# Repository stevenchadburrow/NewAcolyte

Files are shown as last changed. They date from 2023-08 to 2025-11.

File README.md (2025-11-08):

# NewAcolyte

This is the New Acolyte microcomputer.  

It runs a W65C02 microprocessor at 6.29 MHz, and has 64 KB of RAM and 32 KB of ROM available.  It can output 16-colors at a 256x240 resolution, or 4-colors at 512x240 resolution.  It supports PS/2 Keyboard and Mouse, Genesis Gamepad, square wave audio output, and SD Card through SPI adapter.  This New Acolyte uses the Xilinx XC9572XL CLPD, programmed using Xilinx ISE and 'xc3sprog'.  

Currently it's software includes the Scratchpad, Monitor, BASIC, and games including Tetra, Intruders, Missile, Galian, and Knave.

(Bodge wire connects V-SYNC to /NMI. Additional pull-up resistors on JOY-UP, JOY-DOWN, JOY-BUTTON1, and JOY-BUTTON2. Additional pull-down resistor on ROM-BANK.)

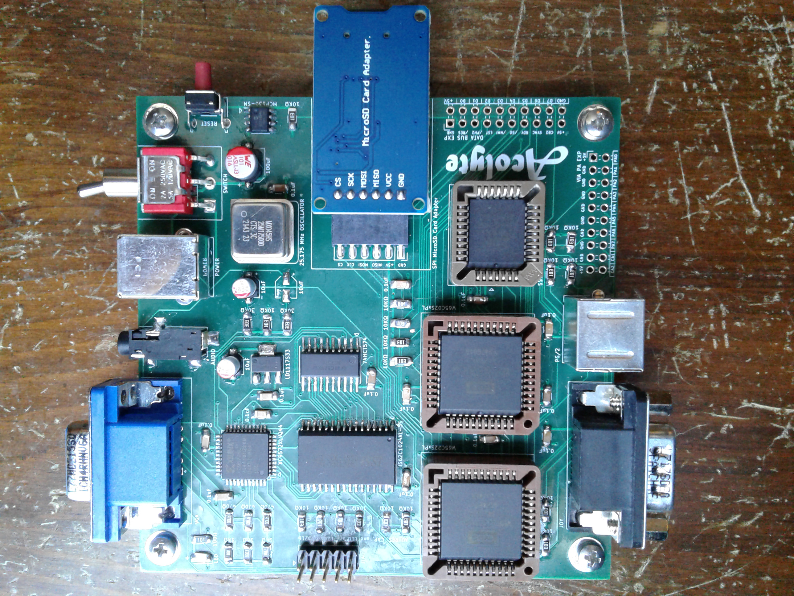
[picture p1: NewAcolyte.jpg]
<br>
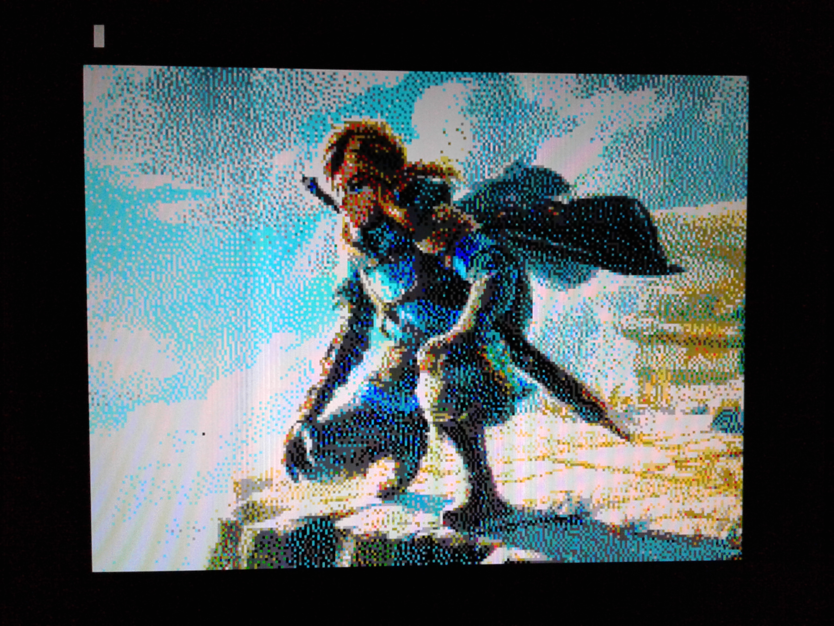
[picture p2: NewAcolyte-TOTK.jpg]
<br>
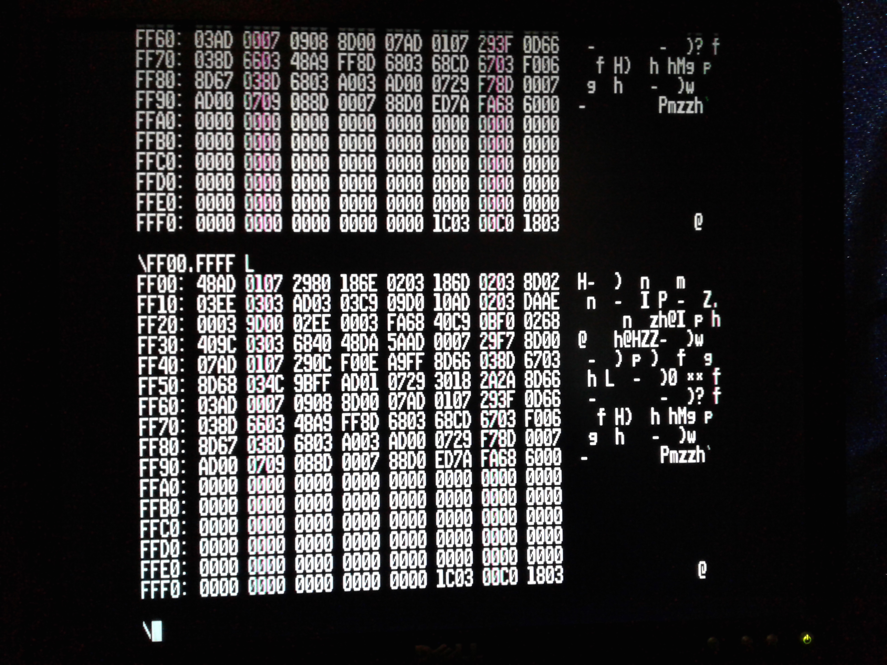
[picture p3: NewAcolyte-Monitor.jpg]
<br>
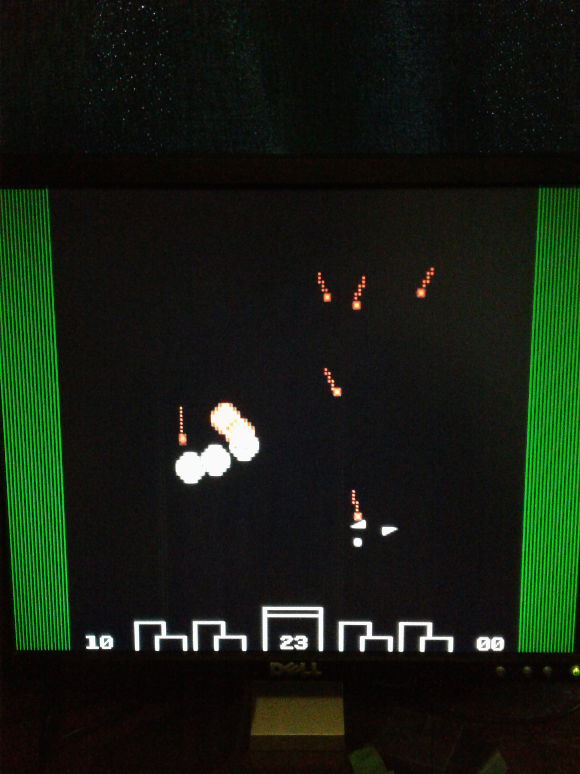
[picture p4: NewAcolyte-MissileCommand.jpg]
<br>
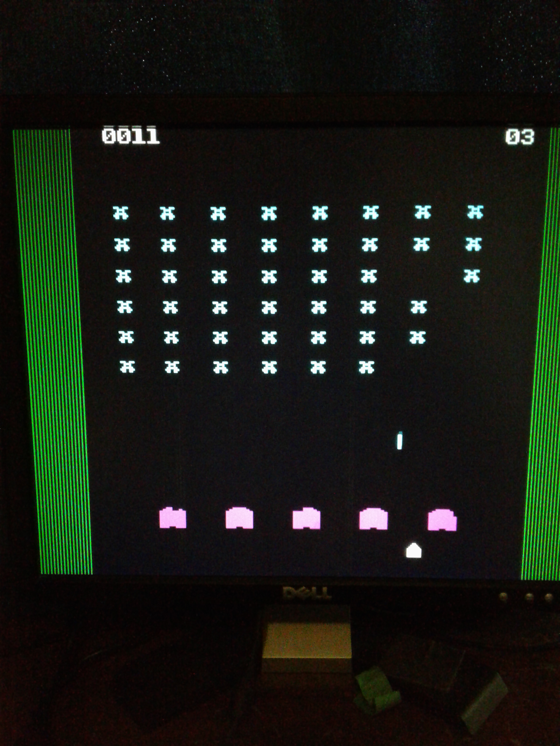
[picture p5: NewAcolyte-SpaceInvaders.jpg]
<br>

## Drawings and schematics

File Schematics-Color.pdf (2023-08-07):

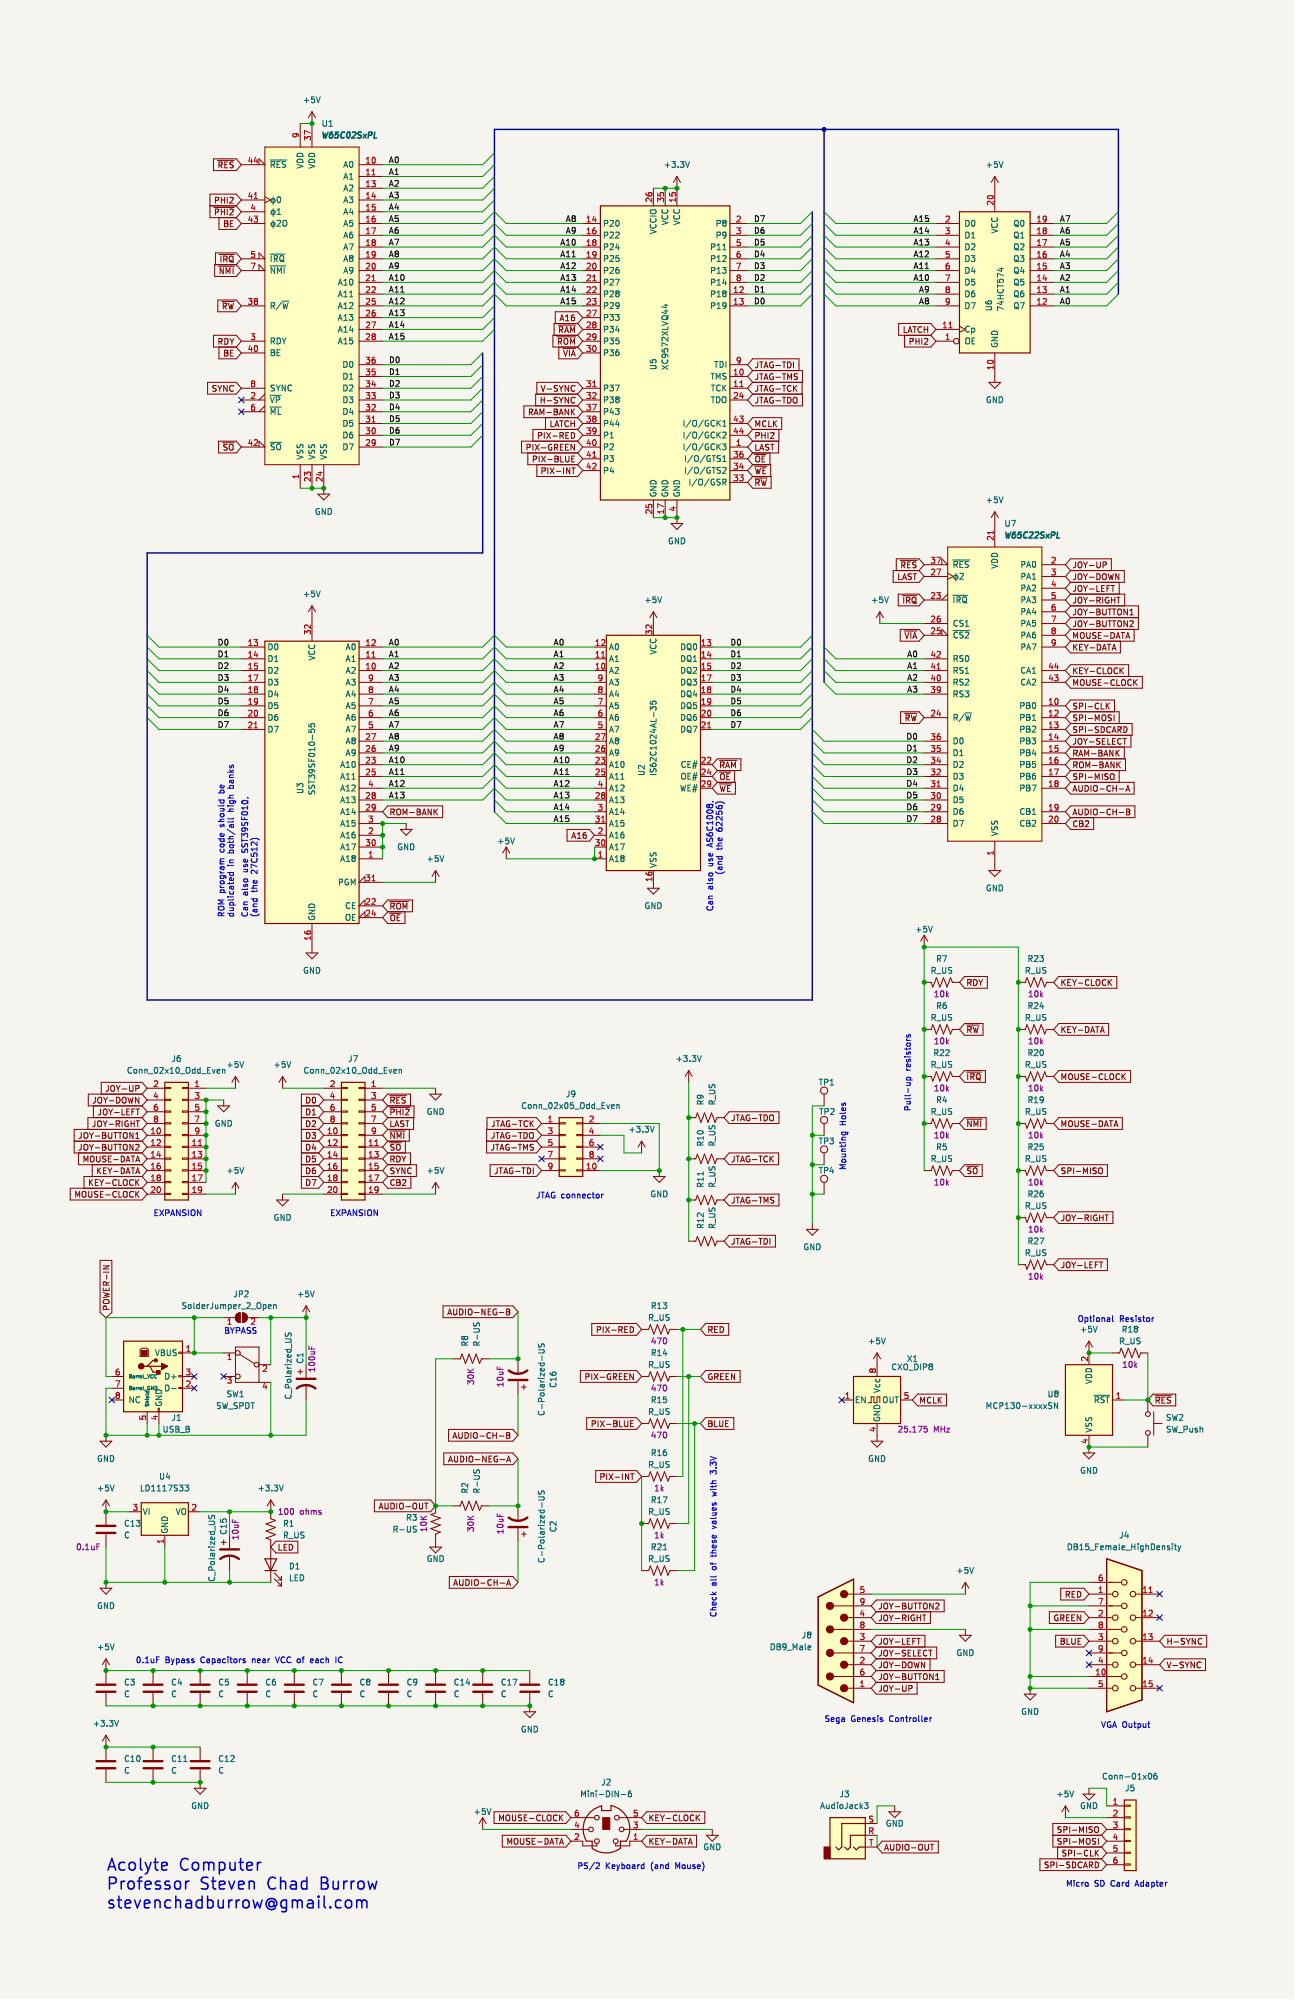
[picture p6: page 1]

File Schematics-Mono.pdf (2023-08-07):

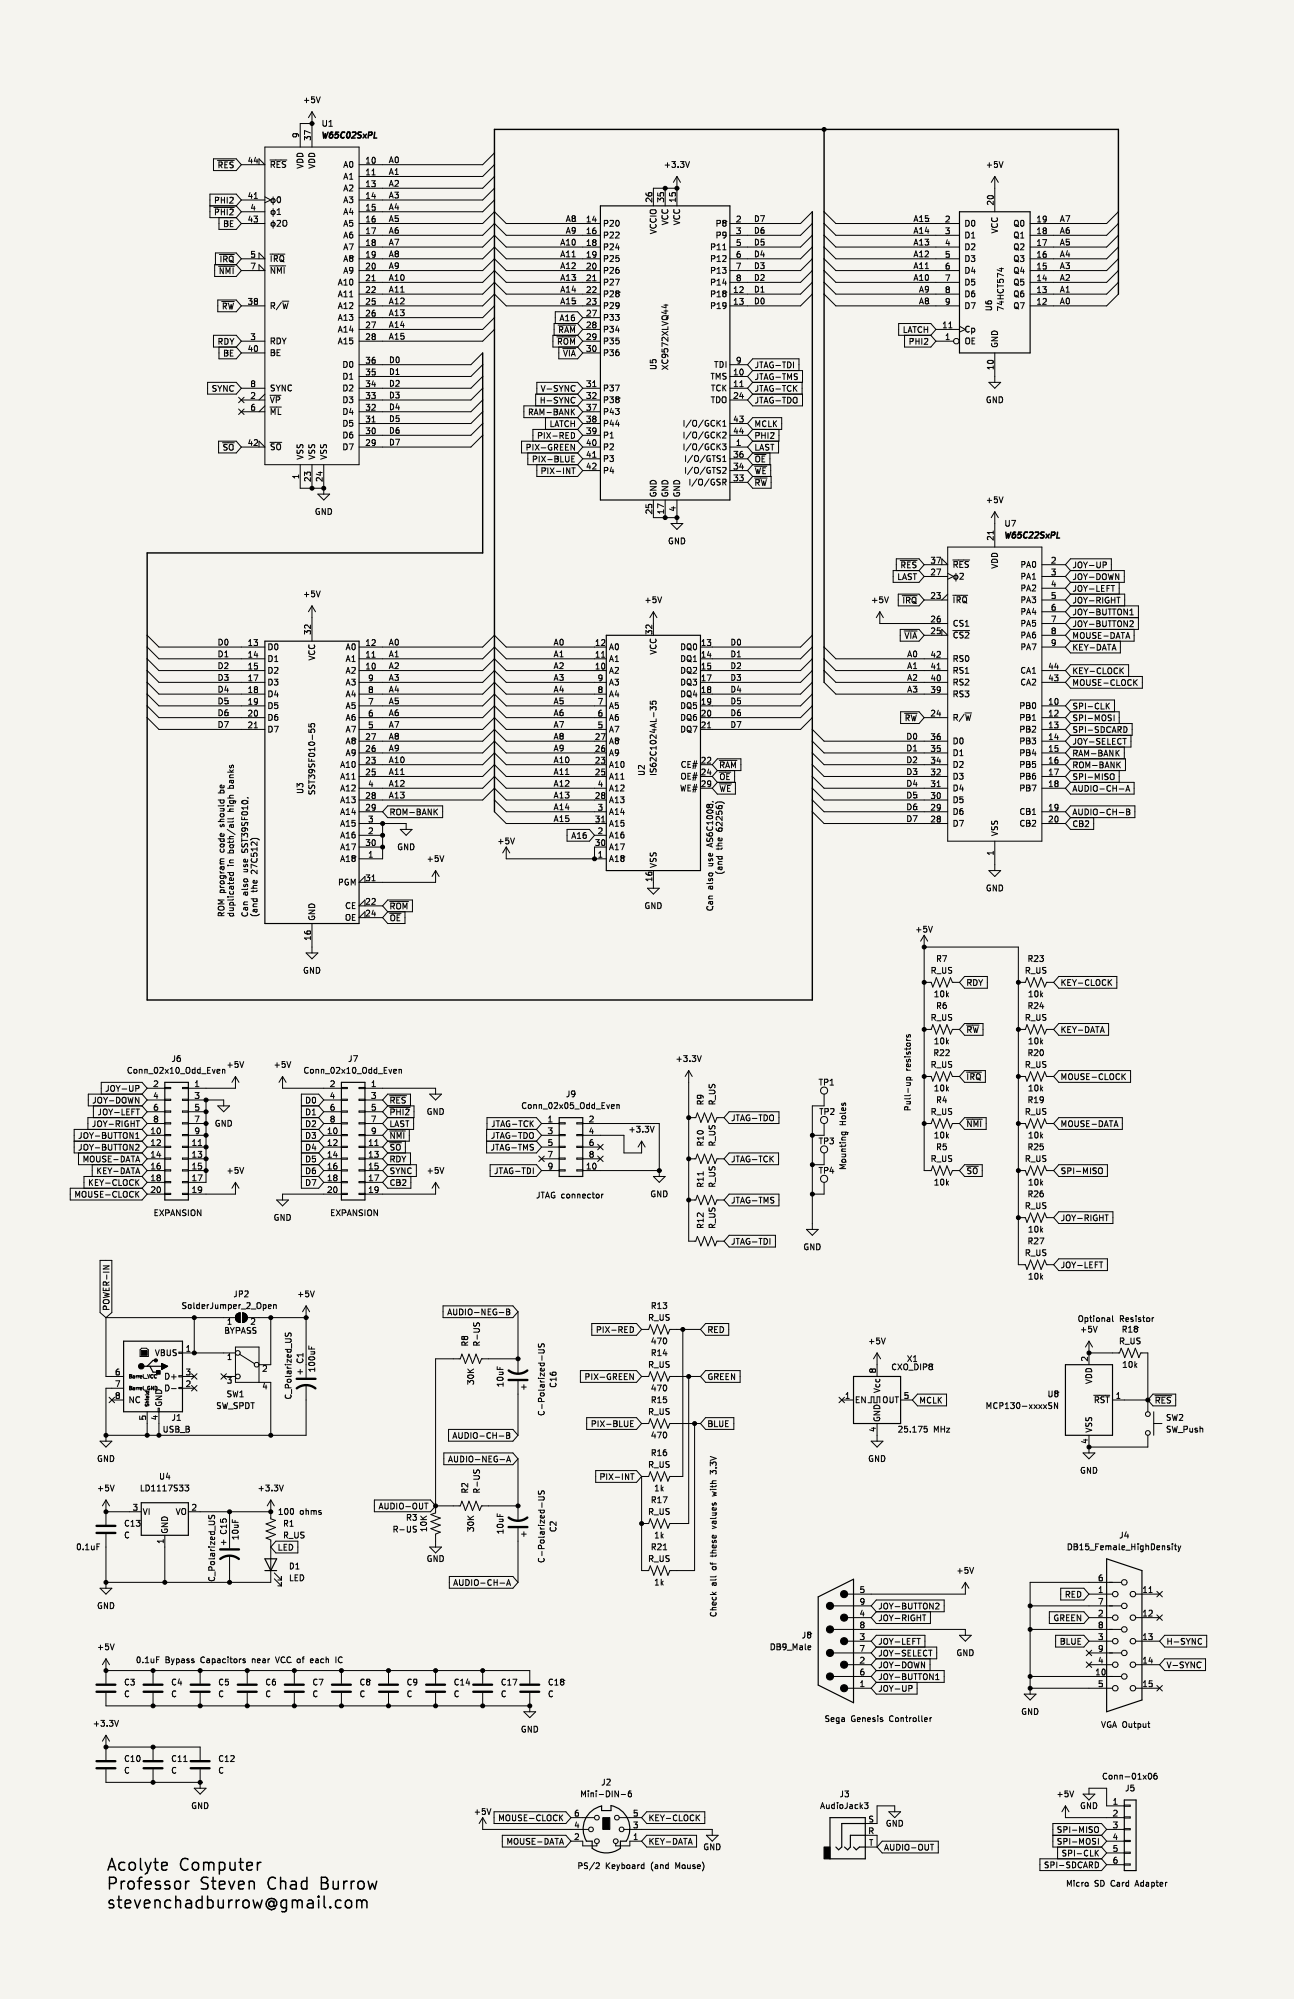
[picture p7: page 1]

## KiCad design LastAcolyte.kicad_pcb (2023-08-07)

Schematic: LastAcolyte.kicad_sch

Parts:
C1: C_Polarized_US; CP_Elec_6.3x5.4
C2, C16: C-Polarized-US; CP_Elec_4x5.4
C3, C4, C5, C6, C7, C8, C9, C10, C11, C12, C13, C14, C17, C18: C; C_1206_3216Metric_Pad1.33x1.80mm_HandSolder
C15: C_Polarized_US; CP_Elec_4x5.4
D1: LED; LED_1206_3216Metric_Pad1.42x1.75mm_HandSolder
J1: USB_B; DualPowerSupply
J2: Mini-DIN-6; PS2_Din6
J3: AudioJack3; Jack_3.5mm_CUI_custom_SJ-3524-SMT_Horizontal
J4: DB15_Female_HighDensity; DSUB-15-HD_Female_Horizontal_P2.29x2.54mm_VGA
J5: Conn-01x06; SDcardPinSocket-Plus
J6, J7: Conn_02x10_Odd_Even; PinHeader_2x10_P2.54mm_Horizontal
J8: DB9_Male; DSUB-9-custom_Male_Horizontal_P2.77x2.84mm_EdgePinOffset7.7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
J9: Conn_02x05_Odd_Even; PinHeader_2x05_P2.54mm_Vertical
JP2: SolderJumper_2_Open; SolderJumper_Testing-2_P1.3mm_Open_Pad1.0x1.5mm
R1, R4, R5, R6, R7, R9, R10, R11, R12, R13, R14, R15, R16, R17, R18, R19, R20, R21, R22, R23, R24, R25, R26, R27: R_US; R_1206_3216Metric_Pad1.30x1.75mm_HandSolder
R2, R3, R8: R-US; R_1206_3216Metric_Pad1.30x1.75mm_HandSolder
SW1: SW_SPDT; SPDT-100SP1T2B4M6QE
SW2: SW_Push; SW_Tactile_SPST_Angled_PTS645Vx83-2LFS
TP1, TP2, TP3, TP4: TestPoint; ScrewHole-4-40
U1: W65C02SxPL; PLCC-44_THT-Socket
U2: IS62C1024AL-35; SSOP-32_11.305x20.495mm_P1.27mm
U3: SST39SF010-55; PLCC-32_THT-Socket
U4: LD1117S33; SOT-223-3_TabPin2
U5: XC9572XLVQ44; TQFP-44_10x10mm_P0.8mm
U6: 74HCT574; SOIC-20W_7.5x12.8mm_P1.27mm
U7: W65C22SxPL; PLCC-44_THT-Socket
U8: MCP130-xxxxSN; SOIC-8_3.9x4.9mm_P1.27mm
X1: CXO_DIP8; Oscillator_DIP-8-custom

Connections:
+3.3V: C10.1, C11.1, C12.1, C15.1, J9.4, R1.2, R9.1, R10.1, R11.1, R12.1, U4.2 (VO), U5.15 (VCC), U5.26 (VCCIO), U5.35 (VCC)
+5V: C1.1, C3.1, C4.1, C5.1, C6.1, C7.1, C8.1, C9.1, C13.1, C14.1, C17.1, C18.1, J2.4, J5.2, J6.1, J6.19, J7.2, J7.19, J8.5, JP2.2 (B), R4.1, R5.1, R6.1, R7.2, R18.1, R19.2, R20.2, R22.2, R23.1, R24.1, R25.2, R26.2, R27.2, SW1.2 (B), U1.9 (VDD), U1.37 (VDD), U2.1 (A18), U2.30 (A17), U2.32 (VCC), U3.31 (PGM), U3.32 (VCC), U4.3 (VI), U6.20 (VCC), U7.21 (VDD), U7.26 (CS1), U8.2 (VDD), X1.8 (Vcc)
/A0: U1.10 (A0), U2.12 (A0), U3.12 (A0), U6.12 (Q7), U7.42 (RS0)
/A1: U1.11 (A1), U2.11 (A1), U3.11 (A1), U6.13 (Q6), U7.41 (RS1)
/A2: U1.13 (A2), U2.10 (A2), U3.10 (A2), U6.14 (Q5), U7.40 (RS2)
/A3: U1.14 (A3), U2.9 (A3), U3.9 (A3), U6.15 (Q4), U7.39 (RS3)
/A4: U1.15 (A4), U2.8 (A4), U3.8 (A4), U6.16 (Q3)
/A5: U1.16 (A5), U2.7 (A5), U3.7 (A5), U6.17 (Q2)
/A6: U1.17 (A6), U2.6 (A6), U3.6 (A6), U6.18 (Q1)
/A7: U1.18 (A7), U2.5 (A7), U3.5 (A7), U6.19 (Q0)
/A8: U1.19 (A8), U2.27 (A8), U3.27 (A8), U5.14 (P20), U6.9 (D7)
/A9: U1.20 (A9), U2.26 (A9), U3.26 (A9), U5.16 (P22), U6.8 (D6)
/A10: U1.21 (A10), U2.23 (A10), U3.23 (A10), U5.18 (P24), U6.7 (D5)
/A11: U1.22 (A11), U2.25 (A11), U3.25 (A11), U5.19 (P25), U6.6 (D4)
/A12: U1.25 (A12), U2.4 (A12), U3.4 (A12), U5.20 (P26), U6.5 (D3)
/A13: U1.26 (A13), U2.28 (A13), U3.28 (A13), U5.21 (P27), U6.4 (D2)
/A14: U1.27 (A14), U2.3 (A14), U5.22 (P28), U6.3 (D1)
/A15: U1.28 (A15), U2.31 (A15), U5.23 (P29), U6.2 (D0)
A16: U2.2 (A16), U5.27 (P33)
AUDIO-CH-A: C2.1, U7.18 (PB7)
AUDIO-CH-B: C16.1, U7.19 (CB1)
AUDIO-NEG-A: C2.2, R2.2
AUDIO-NEG-B: C16.2, R8.2
AUDIO-OUT: J3.R, J3.T, R2.1, R3.1, R8.1
BE: U1.40 (BE), U1.43 (ϕ2O)
BLUE: J4.3, R15.2, R21.2
CB2: J7.17, U7.20 (CB2)
D0: J7.4, U1.36 (D0), U2.13 (DQ0), U3.13 (D0), U5.13 (P19), U7.36 (D0)
D1: J7.6, U1.35 (D1), U2.14 (DQ1), U3.14 (D1), U5.12 (P18), U7.35 (D1)
D2: J7.8, U1.34 (D2), U2.15 (DQ2), U3.15 (D2), U5.8 (P14), U7.34 (D2)
D3: J7.10, U1.33 (D3), U2.17 (DQ3), U3.17 (D3), U5.7 (P13), U7.32 (D3)
D4: J7.12, U1.32 (D4), U2.18 (DQ4), U3.18 (D4), U5.6 (P12), U7.31 (D4)
D5: J7.14, U1.31 (D5), U2.19 (DQ5), U3.19 (D5), U5.5 (P11), U7.30 (D5)
D6: J7.16, U1.30 (D6), U2.20 (DQ6), U3.20 (D6), U5.3 (P9), U7.29 (D6)
D7: J7.18, U1.29 (D7), U2.21 (DQ7), U3.21 (D7), U5.2 (P8), U7.28 (D7)
GND: C1.2, C3.2, C4.2, C5.2, C6.2, C7.2, C8.2, C9.2, C10.2, C11.2, C12.2, C13.2, C14.2, C15.2, C17.2, C18.2, D1.1 (K), J1.4 (GND), J1.5 (Shield), J1.7 (Barrel_GND), J2.3, J3.S, J4.5, J4.6, J4.7, J4.8, J4.10, J5.1, J6.3, J6.5, J6.7, J6.9, J6.11, J6.13, J6.15, J6.17, J7.1, J7.20, J8.8, J9.2, J9.10, R3.2, SW1.4 (Shield), SW2.2, TP1.1, TP2.1, TP3.1, TP4.1, U1.1 (VSS), U1.23 (VSS), U1.24 (VSS), U2.16 (VSS), U3.1 (A18), U3.2 (A16), U3.3 (A15), U3.16 (GND), U3.30 (A17), U4.1 (GND), U5.4 (GND), U5.17 (GND), U5.25 (GND), U6.10 (GND), U7.1 (VSS), U8.4 (VSS), X1.4 (GND)
GREEN: J4.2, R14.2, R17.2
H-SYNC: J4.13, U5.32 (P38)
JOY-BUTTON1: J6.10, J8.6, U7.6 (PA4)
JOY-BUTTON2: J6.12, J8.9, U7.7 (PA5)
JOY-DOWN: J6.4, J8.2, U7.3 (PA1)
JOY-LEFT: J6.6, J8.3, R27.1, U7.4 (PA2)
JOY-RIGHT: J6.8, J8.4, R26.1, U7.5 (PA3)
JOY-SELECT: J8.7, U7.14 (PB3)
JOY-UP: J6.2, J8.1, U7.2 (PA0)
JTAG-TCK: J9.1, R10.2, U5.11 (TCK)
JTAG-TDI: J9.9, R12.2, U5.9 (TDI)
JTAG-TDO: J9.3, R9.2, U5.24 (TDO)
JTAG-TMS: J9.5, R11.2, U5.10 (TMS)
KEY-CLOCK: J2.5, J6.18, R23.2, U7.44 (CA1)
KEY-DATA: J2.1, J6.16, R24.2, U7.9 (PA7)
LAST: J7.7, U5.1 (I/O/GCK3), U7.27 (ϕ2)
LATCH: U5.38 (P44), U6.11 (Cp)
LED: D1.2 (A), R1.1
MCLK: U5.43 (I/O/GCK1), X1.5 (OUT)
MOUSE-CLOCK: J2.6, J6.20, R20.1, U7.43 (CA2)
MOUSE-DATA: J2.2, J6.14, R19.1, U7.8 (PA6)
PHI2: U1.41 (ϕ0), U5.44 (I/O/GCK2), U6.1 (OE)
PIX-BLUE: R15.1, U5.41 (P3)
PIX-GREEN: R14.1, U5.40 (P2)
PIX-INT: R16.1, R17.1, R21.1, U5.42 (P4)
PIX-RED: R13.1, U5.39 (P1)
POWER-IN: J1.1 (VBUS), J1.6 (Barrel_VCC), JP2.1 (A), SW1.1 (A)
RAM-BANK: U5.37 (P43), U7.15 (PB4)
RDY: J7.13, R7.1, U1.3 (RDY)
RED: J4.1, R13.2, R16.2
ROM-BANK: U3.29 (A14), U7.16 (PB5)
SPI-CLK: J5.5, U7.10 (PB0)
SPI-MISO: J5.3, R25.1, U7.17 (PB6)
SPI-MOSI: J5.4, U7.12 (PB1)
SPI-SDCARD: J5.6, U7.13 (PB2)
SYNC: J7.15, U1.8 (SYNC)
V-SYNC: J4.14, U5.31 (P37)
~IRQ: R22.1, U1.5 (~IRQ), U7.23 (~IRQ)
~NMI: J7.9, R4.2, U1.7 (~NMI)
~OE: U2.24 (OE#), U3.24 (OE), U5.36 (I/O/GTS1)
~PHI2: J7.5, U1.4 (ϕ1)
~RAM: U2.22 (CE#), U5.28 (P34)
~RES: J7.3, R18.2, SW2.1, U1.44 (~RES), U7.37 (~RES), U8.1 (~RST)
~ROM: U3.22 (CE), U5.29 (P35)
~RW: R6.2, U1.38 (R/~W), U5.33 (I/O/GSR), U7.24 (R/~W)
~SO: J7.11, R5.2, U1.42 (~SO)
~VIA: U5.30 (P36), U7.25 (~CS2)
~WE: U2.29 (WE#), U5.34 (I/O/GTS2)

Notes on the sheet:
0.1uF Bypass Capacitors near VCC of each IC
Acolyte Computer Steven Chad Burrow 2023, Public Domain
Can also use AS6C1008, (and the 62256)
Optional Resistor
Can also use SST39SF010, (and the 27C512)
Micro SD Card Adapter
Sega Genesis Controller
EXPANSION
http://falstad.com/circuit/circuitjs.html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…
Check all of these values with 3.3V
VGA Output
Pull-up resistors
BYPASS
ROM program code should be duplicated in both/all high banks
PS/2 Keyboard (and Mouse)
VGA graphics resolutions: 256x240 at 16-colors 512x240 at 4-colors PS/2 Keyboard and Mouse Genesis Controller SPI SD Card Square Wave Audio W65C02 running at 6.29 MHz 2KB System RAM 30KB Video RAM 32KB General RAM (2 banks of 16KB) 32KB Program ROM (2 banks of 16KB) Memory Map: $0000-$07FF = System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
Acolyte Computer Professor Steven Chad Burrow stevenchadburrow@gmail.com
Mounting Holes
JTAG connector

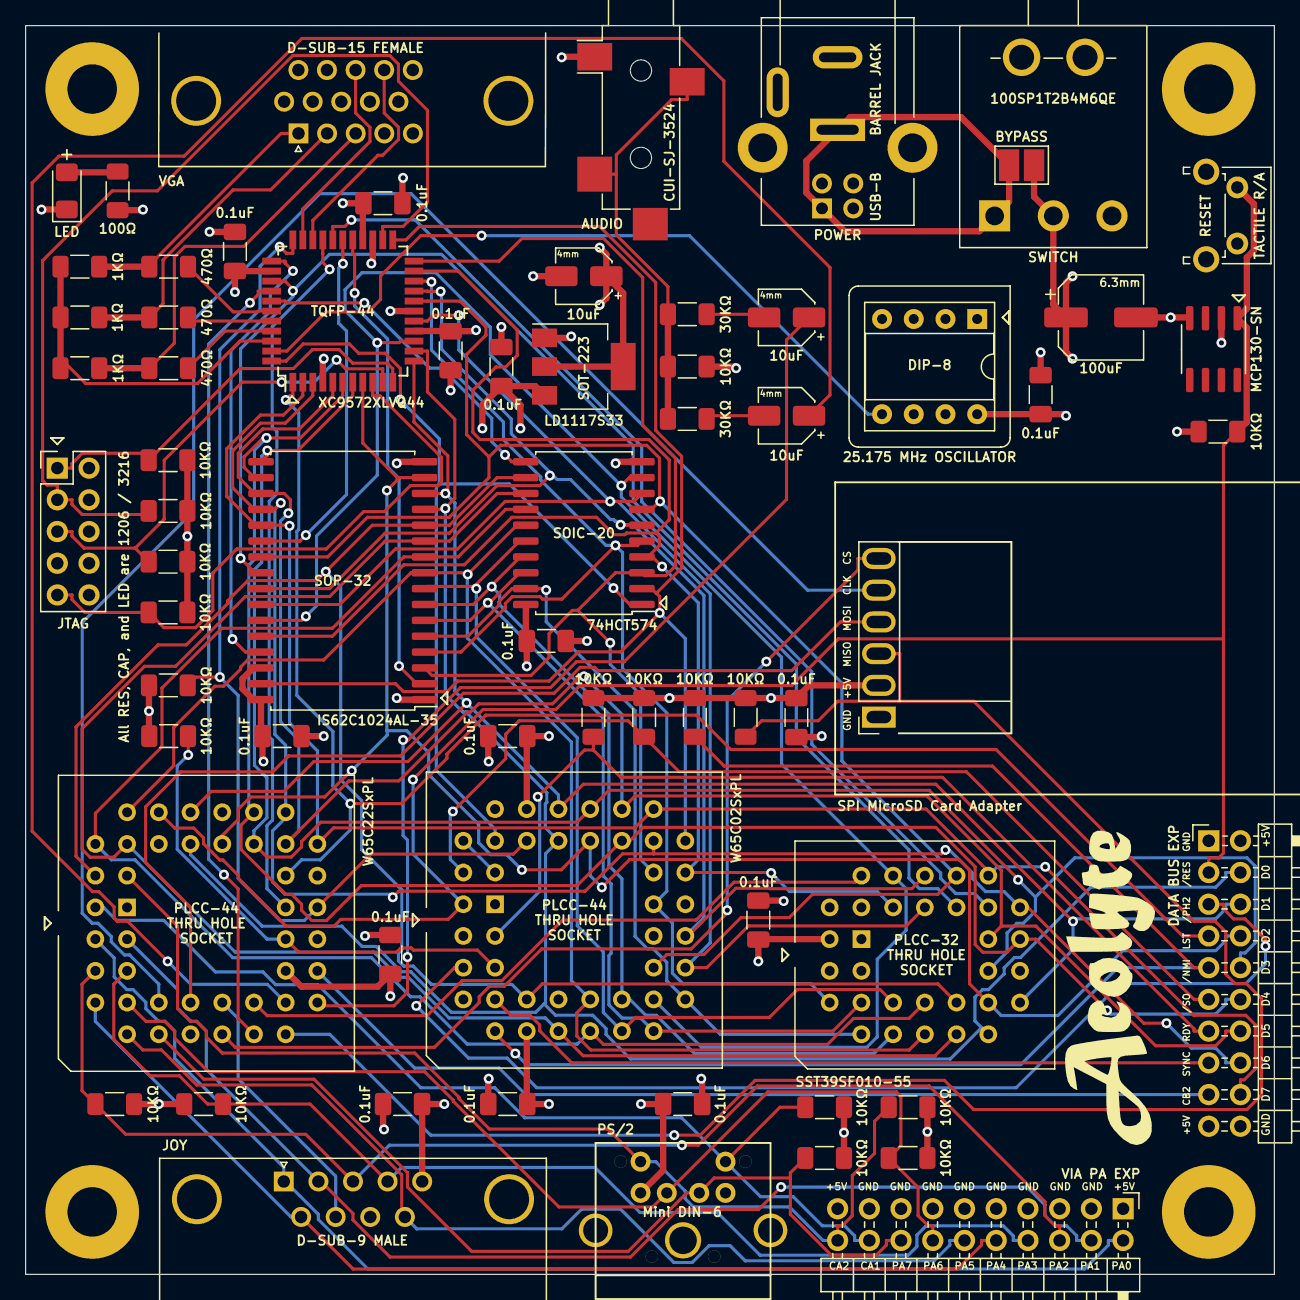
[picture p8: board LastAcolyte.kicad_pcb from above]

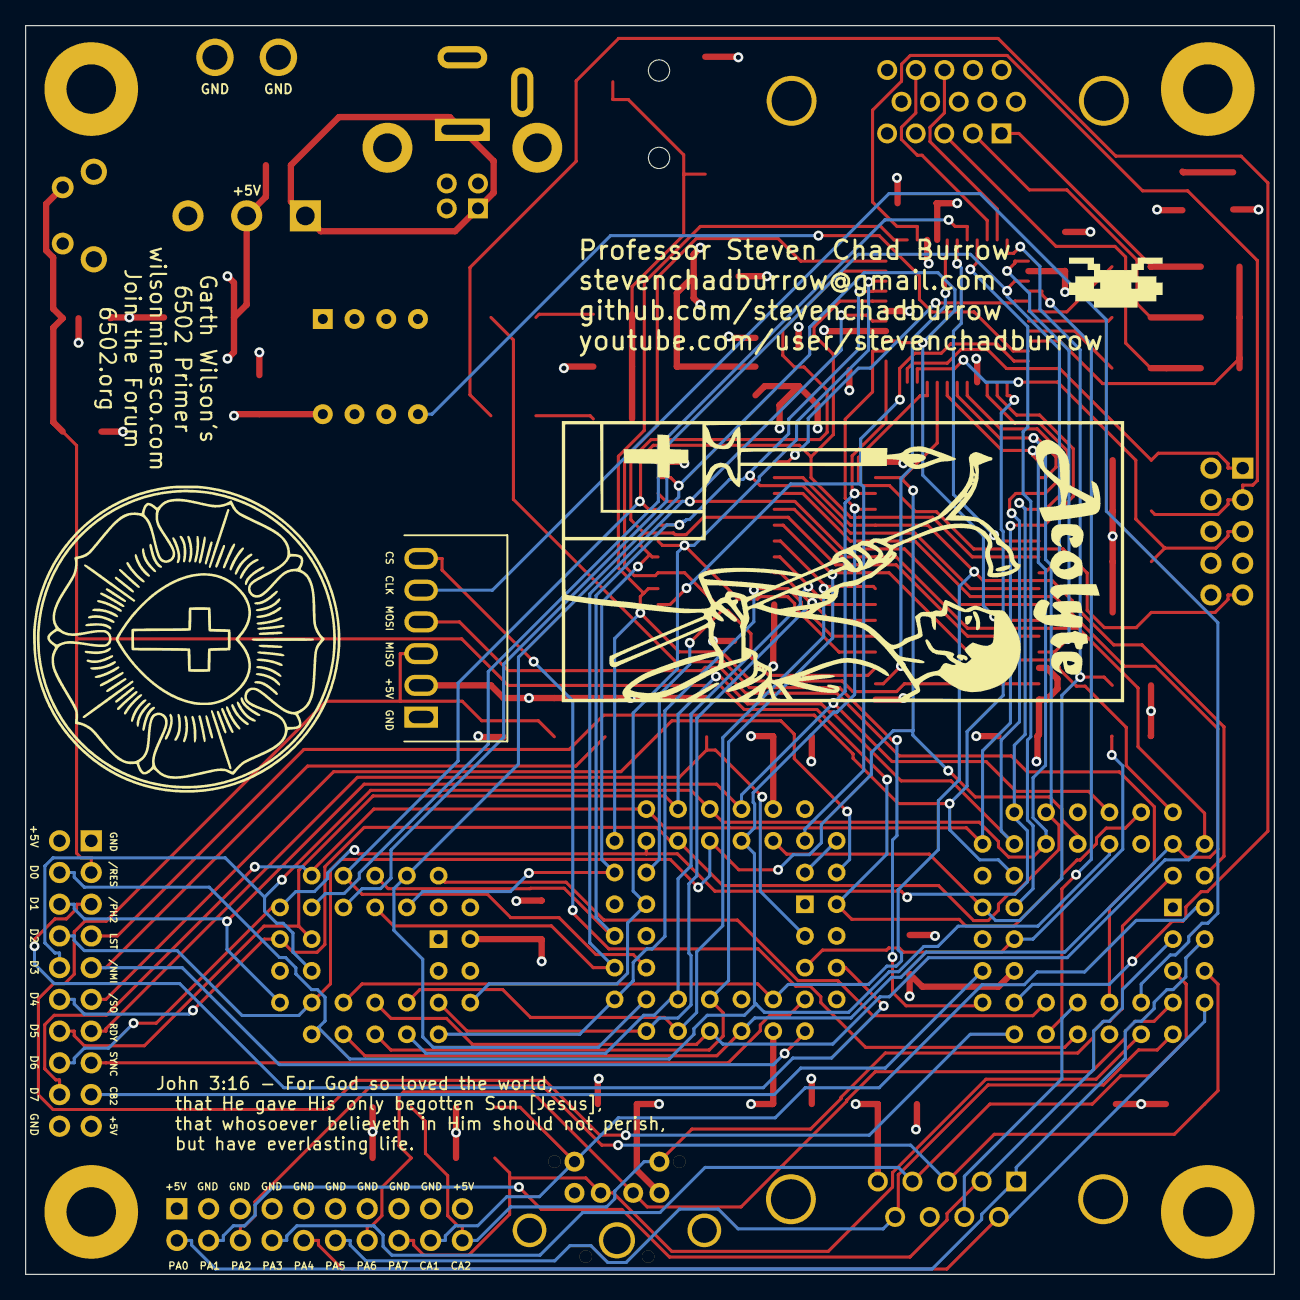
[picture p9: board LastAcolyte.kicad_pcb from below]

Board: 4 copper layers, 100.0 x 100.0 mm, 75 parts (3 on the bottom side), 84 nets.

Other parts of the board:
G101: LOGO; AcolyteLogoSmall
G102: LOGO; Mystery
G103: LOGO; LutheranRosePD
G104: LOGO; AcolyteName

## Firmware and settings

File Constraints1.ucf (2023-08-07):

NET address[0] LOC = P14;
NET address[1] LOC = P16;
NET address[2] LOC = P18;
NET address[3] LOC = P19;

NET address[4] LOC = P20;
NET address[5] LOC = P21;
NET address[6] LOC = P22;
NET address[7] LOC = P23;

NET addr16 LOC = P27;

NET ram LOC = P28;
NET rom LOC = P29;
NET via LOC = P30;

NET vsync LOC = P31;
NET hsync LOC = P32;

NET bank LOC = P37;
NET latch LOC = P38;

NET red LOC = P39;
NET green LOC = P40;
NET blue LOC = P41;
NET intensity LOC = P42;

NET data[7] LOC = P2;
NET data[6] LOC = P3;
NET data[5] LOC = P5;
NET data[4] LOC = P6;

NET data[3] LOC = P7;
NET data[2] LOC = P8;
NET data[1] LOC = P12;
NET data[0] LOC = P13;

NET master_clock LOC = P43;
NET phi2 LOC = P44;
NET last LOC = P1;

NET oe LOC = P36;
NET we LOC = P34;
NET rw LOC = P33;

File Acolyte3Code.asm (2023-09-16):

; Acolyte 3 Computer Code

; First, run
; ~/dev65/bin/as65 Acolyte3Code.asm

; Second, run
; ./Parser.o Acolyte3Code.lst Acolyte3Code.bin 49152 0 16384 0

; Third, run
; ~/dev65/bin/as65 Acolyte3Code-Bank2.asm

; Fourth, run
; ./Parser.o Acolyte3Code-Bank2.lst Acolyte3Code-Bank2.bin 49152 0 16384 0

; Fifth, run
; ./Combiner.o Acolyte3Code.bin Acolyte3Code-Bank2.bin Acolyte3Code-Combined.bin

; Third, run
; minipro -p "SST39SF010" -w Acolyte3Code.bin

; OR
; ./AcolyteSimulator.o Acolyte3Code.bin

; Altogether
; ~/dev65/bin/as65 Acolyte3Code.asm ; ./Parser.o Acolyte3Code.lst Acolyte3Code.bin 49152 0 16384 0 ; ~/dev65/bin/as65 Acolyte3Code-Bank2.asm ; ./Parser.o Acolyte3Code-Bank2.lst Acolyte3Code-Bank2.bin 49152 0 16384 0 ; ./Combiner.o Acolyte3Code.bin Acolyte3Code-Bank2.bin Acolyte3Code-Combined.bin



; Acolyte Computer

; Running a W65C02 at 6.29 MHz

; VGA display at
; 256x240 16-color
; and
; 512x240 4-color

; Support for
; PS/2 Keyboard and Mouse
; Genesis Gamepad
; SPI SDcard
; 2-Voice Square Wave Audio

; Memory Map
; $0000-$01FF = Zero Page / Stack
; $0200-$06FF = System RAM
; $0700-$07FF = VIA
; $0800-$7FFF = Video RAM
; $8000-$BFFF = General Purpose RAM (2x banks)
; $C000-$FFFF = ROM (2x banks)

; Writing to ROM changes the video mode
; If writing $00 to ROM, video mode is 256x240 16-color
; Else, the upper and lower nibbles determine the colors
; used in 512x240 4-color mode.  
; Black and White are always available, but other two
; colors are defined when entering that mode.

; VIA pins
; PA0 = JOY-UP
; PA1 = JOY-DOWN
; PA2 = JOY-LEFT (with 10K pull-up)
; PA3 = JOY-RIGHT (with 10K pull-up)
; PA4 = JOY-BUTTON1
; PA5 = JOY-BUTTON2
; PA6 = MOUSE-DATA
; PA7 = KEY-DATA
; CA1 = KEY-CLOCK
; CA2 = MOUSE-CLOCK
; PB0 = SPI-CLOCK
; PB1 = SPI-MOSI
; PB2 = SPI-CS (for SDCARD)
; PB3 = JOY-SELECT
; PB4 = RAM-BANK
; PB5 = ROM-BANK
; PB6 = SPI-MISO
; PB7 = AUDIO-CH-A
; CB1 = AUDIO-CH-B
; CB2 = Unused

; /NMI is connected to V-SYNC through a bodge wire


	.65C02


; PS/2 Keyboard Keycodes
ps2_space		.EQU $29
ps2_return		.EQU $5A
ps2_backspace		.EQU $66
ps2_escape		.EQU $76
ps2_shift_left		.EQU $12
ps2_shift_right		.EQU $59
ps2_capslock		.EQU $58
ps2_numlock		.EQU $77
ps2_scrolllock		.EQU $7E
ps2_control		.EQU $14
ps2_alt			.EQU $11
ps2_tab			.EQU $0D
ps2_page_up		.EQU $7D
ps2_page_down		.EQU $7A
ps2_arrow_up		.EQU $75
ps2_arrow_down		.EQU $72
ps2_arrow_left		.EQU $6B
ps2_arrow_right		.EQU $74
ps2_insert		.EQU $70
ps2_delete		.EQU $71
ps2_home		.EQU $6C
ps2_end			.EQU $69
ps2_slash		.EQU $4A
ps2_f1			.EQU $05
ps2_f2			.EQU $06
ps2_f3			.EQU $04
ps2_f4			.EQU $0C
ps2_f5			.EQU $03
ps2_f6			.EQU $0B
ps2_f7			.EQU $83
ps2_f8			.EQU $0A
ps2_f9			.EQU $01
ps2_f10			.EQU $09
ps2_f11			.EQU $78
ps2_f12			.EQU $07


; VIA locations

via			.EQU $0700 ; full page
via_pb			.EQU via+$00
via_pa			.EQU via+$01
via_db			.EQU via+$02
via_da			.EQU via+$03
via_t1cl		.EQU via+$04
via_t1ch		.EQU via+$05
via_t2cl		.EQU via+$08
via_t2ch		.EQU via+$09
via_acr			.EQU via+$0B
via_pcr			.EQU via+$0C
via_ifr			.EQU via+$0D
via_ier			.EQU via+$0E
via_pah			.EQU via+$0F ; via_pa without handshake

spi_clk			.EQU %00000001
spi_clk_inv		.EQU %11111110
spi_mosi		.EQU %00000010
spi_mosi_inv		.EQU %11111101
spi_cs			.EQU %00000100
spi_cs_inv		.EQU %11111011
spi_miso		.EQU %01000000
spi_miso_inv		.EQU %10111111

joy_select		.EQU %00001000
joy_select_inv		.EQU %11110111


; System RAM locations

key_array		.EQU $0200

key_write		.EQU $0280
key_read		.EQU $0281
key_data		.EQU $0282
key_counter		.EQU $0283
key_release		.EQU $0284
key_extended		.EQU $0285
key_shift		.EQU $0286
key_capslock		.EQU $0287
key_alt_control		.EQU $0288

mouse_buttons		.EQU $0289
mouse_pos_x		.EQU $028A
mouse_pos_y		.EQU $028B
mouse_prev_buttons	.EQU $028C
mouse_prev_x		.EQU $028D
mouse_prev_y		.EQU $028E
mouse_data		.EQU $028F
mouse_counter		.EQU $0290
mouse_state		.EQU $0291

joy_buttons		.EQU $0292

sub_random		.EQU $0293 ; 18 bytes long
sub_random_var		.EQU $02A5

clock_low		.EQU $02A6
clock_high		.EQU $02A7

vector_irq		.EQU $02A8 ; 4 bytes long
vector_nmi		.EQU $02AC ; 4 bytes long

sub_jump		.EQU $02B0 ; 4 bytes long
sub_read		.EQU $02B4 ; 4 bytes long
sub_index		.EQU $02B8 ; 4 bytes long
sub_write		.EQU $02BC ; 4 bytes long

sdcard_block		.EQU $02C0 ; 2 bytes 

printchar_x		.EQU $02C2 ; from $00 to $3F
printchar_y		.EQU $02C3 ; from $00 to $1D
printchar_foreground	.EQU $02C4 ; either $00, $55, $AA, or $FF
printchar_background	.EQU $02C5 ; either $00, $55, $AA, or $FF
printchar_inverse	.EQU $02C6 ; either $00 or $FF
printchar_storage	.EQU $02C7
printchar_read		.EQU $02C8 ; 4 bytes long
printchar_write		.EQU $02CC ; 4 bytes long

selector_joy_prev	.EQU $02D2
selector_position	.EQU $02D3

colorchar_input		.EQU $02D0
colorchar_output	.EQU $02D1

monochar_input		.EQU $02D2
monochar_output		.EQU $02D3

displaynum_mode		.EQU $02D4

; unused memory here

; memory from $0300 to $04FF is available for any program
; but changes for each program

command_string		.EQU $0300 ; 64 bytes long

function_mode		.EQU $0340

scratchpad_lastchar	.EQU $0341

monitor_mode		.EQU $0342
monitor_nibble		.EQU $0343
monitor_values		.EQU $0344 ; 8 bytes long

basic_line_low		.EQU $034C
basic_line_high		.EQU $034D
basic_value1_low	.EQU $034E
basic_value1_high	.EQU $034F
basic_value2_low	.EQU $0350
basic_value2_high	.EQU $0351
basic_value3_low	.EQU $0352
basic_value3_high	.EQU $0353
basic_value4_low	.EQU $0354
basic_value4_high	.EQU $0355
basic_character		.EQU $0356
basic_operator		.EQU $0357
basic_wait_end		.EQU $0358
basic_wait_delete	.EQU $0359
basic_variables_low	.EQU $035A ; 26 bytes
basic_variables_high	.EQU $0374 ; 26 bytes
basic_keys		.EQU $038E ; 16 bytes long
basic_keys_plus_one	.EQU $039F
basic_memory		.EQU $8000 ; 16KB available
basic_memory_end	.EQU $C000 ; one past

tetra_score_low		.EQU $0300 ; reusing memory location
tetra_score_high	.EQU $0301
tetra_piece		.EQU $0302
tetra_piece_next	.EQU $0303
tetra_location		.EQU $0304
tetra_speed		.EQU $0305
tetra_overscan		.EQU $0306
tetra_joy_prev		.EQU $0307
tetra_values		.EQU $0308 ; 3 bytes
tetra_field		.EQU $0400 ; 256 bytes long
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
